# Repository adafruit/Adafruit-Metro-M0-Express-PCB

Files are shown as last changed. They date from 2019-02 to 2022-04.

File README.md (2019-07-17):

## Adafruit METRO M0 Express - designed for CircuitPython - ATSAMD21G18 PCB

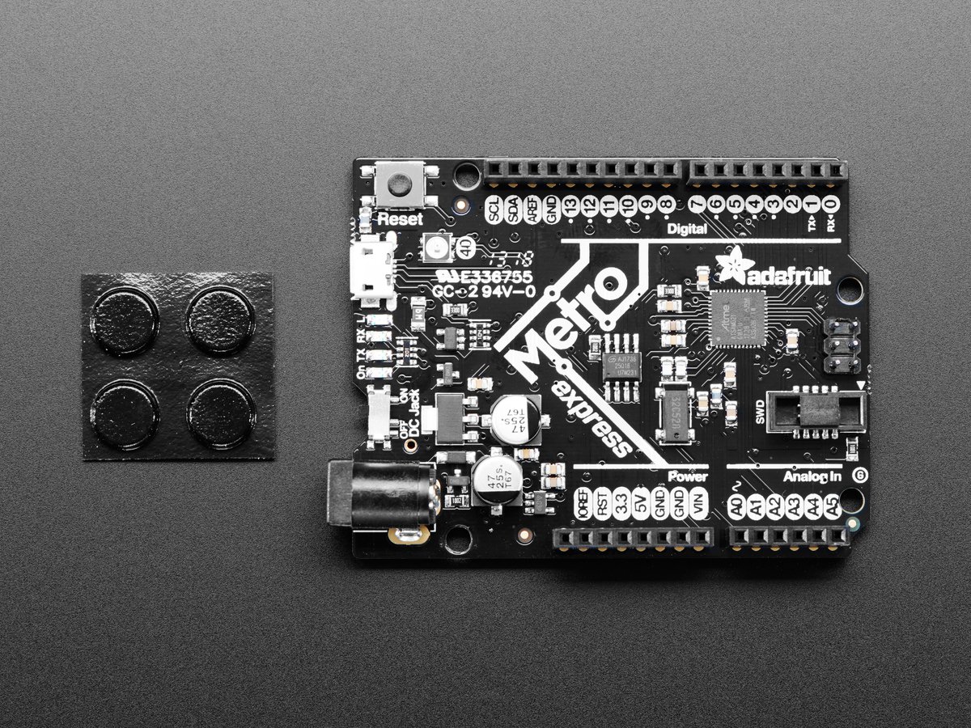
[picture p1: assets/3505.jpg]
<a href="http://www.adafruit.com/products/3505"><br/>
Click here to purchase one from the Adafruit shop</a>

PCB files for the Adafruit METRO M0 Express - designed for CircuitPython - ATSAMD21G18. Format is EagleCAD schematic and board layout
* https://www.adafruit.com/product/3505

### Description

Metro is our series of microcontroller boards for use with the Arduino IDE. This new **Metro M0 Express** board looks a whole lot like our [original Metro 328](https://www.adafruit.com/product/2488), but with a huge upgrade. Instead of the ATmega328, this Metro features a ATSAMD21G18 chip, an ARM Cortex M0+. It's our first Metro that is designed for use with CircuitPython! CircuitPython is our beginner-oriented flavor of MicroPython - and as the name hints at, its a small but full-featured version of the popular Python programming language specifically for use with circuitry and electronics.

Not only can you use CircuitPython, but the Metro M0 is also usable in the Arduino IDE.

At the Metro M0's heart is an ATSAMD21G18 ARM Cortex M0 processor, clocked at 48 MHz and at 3.3V logic, the same one used in the new [Arduino Zero](https://www.adafruit.com/products/2843). This chip has a whopping 256K of FLASH (8x more than the Atmega328) and 32K of RAM (16x as much)! This chip comes with built in USB so it has USB-to-Serial program & debug capability built in with no need for an FTDI-like chip.

 * **Power the METRO** with 7-9V polarity protected DC or the micro USB connector to any 5V USB source. The 2.1mm DC jack has an on/off switch next to it so you can turn off your setup easily. The METRO will automagically switch between USB and DC.
 * **METRO has 25 GPIO pins**, 12 of which are analog in, and one of which is a true analog out. There's a hardware SPI port, hardware I2C port and hardware UART. Logic level is 3.3V
 * **Native USB**, there's no need for a hardware USB to Serial converter as the Metro M0 has built in USB support. When used to act like a serial device, the USB interface can be used by any computer to listen/send data to the METRO, and can also be used to launch and update code via the bootloader. It can also act like a keyboard, mouse or MIDI device as well.
 * **Four indicator LEDs and one NeoPixel**, on the front edge of the PCB, for easy debugging. One green power LED, two RX/TX LEDs for data being sent over USB, and a red LED connected. Next to the reset button there is an RGB NeoPixel that can be used for any purpose.
 * **2 MB SPI Flash** storage chip is included on board. You can use the SPI Flash storage like a very tiny hard drive. When used in Circuit Python, the 2 MB flash acts as storage for all your scripts, libraries and files. When used in Arduino, you can read/write files to it, like a little datalogger or SD card, and then with our helper program, access the files over USB.
 * **Easy reprogramming**, comes pre-loaded with the [UF2 bootloader](https://learn.adafruit.com/adafruit-metro-m0-express-designed-for-circuitpython/uf2-bootloader), which looks like a USB storage key. Simply drag firmware on to program, no special tools or drivers needed! It can be used to load up CircuitPython, PXT/MakeCode or Arduino IDE (it is bossa-compatible)
Comes fully assembled with headers, tested, and with the UF2 bootloader loaded on. We also include 4 rubber bumpers to keep it from slipping off your desk. No soldering required to use, plug and play!

Good news, CircuitPython now comes preloaded!

[Check out our full guide for pinouts, schematics, drivers, instructions, Fritzing object, and more!](https://learn.adafruit.com/adafruit-metro-m0-express-designed-for-circuitpython)

### License

Adafruit invests time and resources providing this open source design, please support Adafruit and open-source hardware by purchasing products from [Adafruit](https://www.adafruit.com)!

Designed by Limor Fried/Ladyada for Adafruit Industries.

Creative Commons Attribution/Share-Alike, all text above must be included in any redistribution. See license.txt for additional details.

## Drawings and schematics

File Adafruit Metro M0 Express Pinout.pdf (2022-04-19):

# Adafruit Metro M0 Express

# https://www.adafruit.com/product/3505

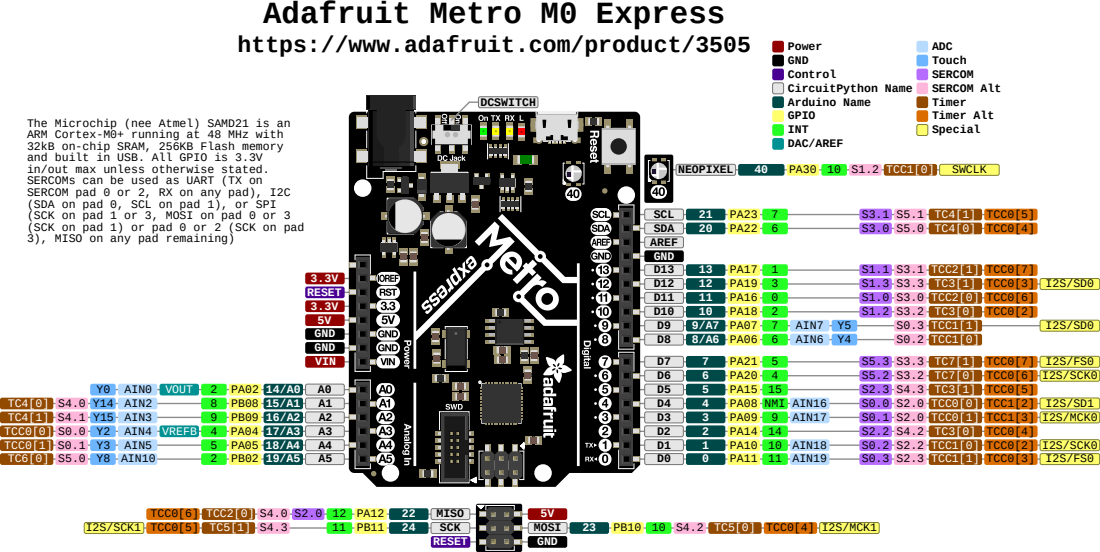
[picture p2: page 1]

The Microchip (nee Atmel) SAMD21 is an
ARM Cortex-M0+ running at 48 MHz with
32kB on-chip SRAM, 256KB Flash memory
and built in USB. All GPIO is 3.3V
in/out max unless otherwise stated.
SERCOMs can be used as UART (TX on
SERCOM pad 0 or 2, RX on any pad), I2C
(SDA on pad 0, SCL on pad 1), or SPI
(SCK on pad 1 or 3, MOSI on pad 0 or 3
(SCK on pad 1) or pad 0 or 2 (SCK on pad
3), MISO on any pad remaining)

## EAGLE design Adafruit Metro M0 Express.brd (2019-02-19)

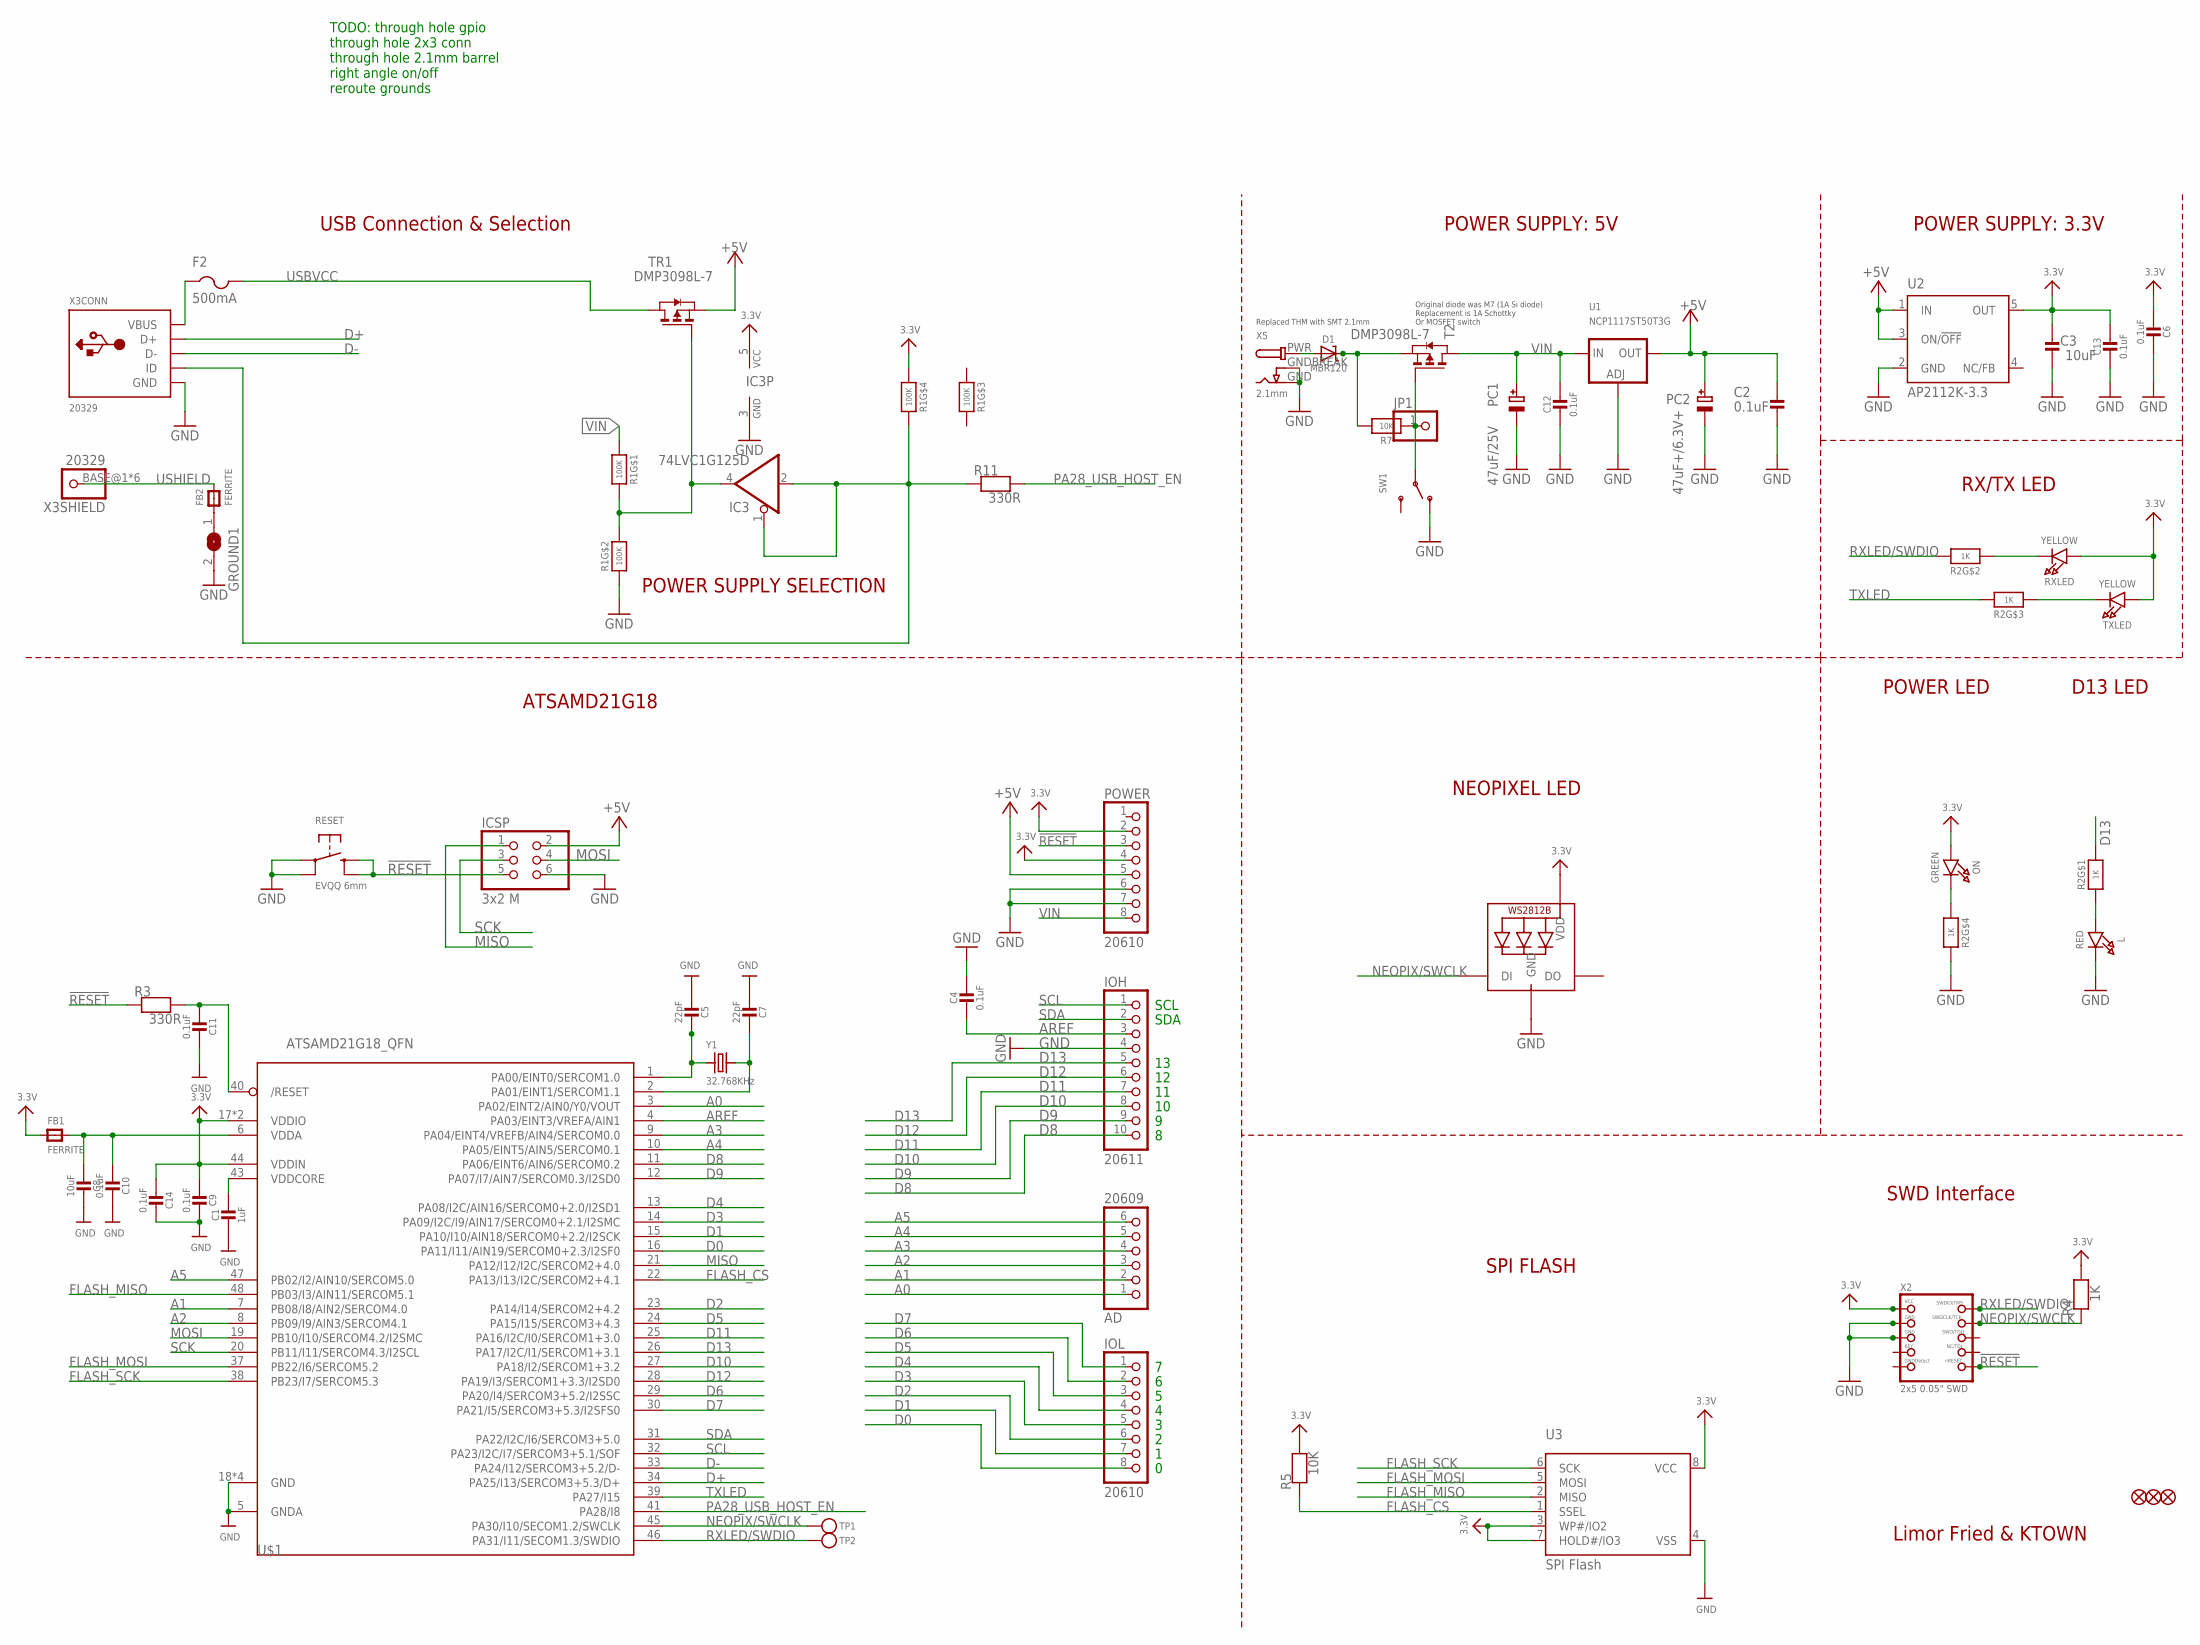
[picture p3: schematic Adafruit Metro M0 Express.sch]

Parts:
AD: 20609; 1X06_OVALWAVE
C1: 1uF; 0805-NO
C2, C4, C6, C9, C10, C11, C12, C13, C14: 0.1uF; 0805-NO
C3, C8: 10uF; 0805-NO
C5, C7: 22pF; 0805-NO
D1: MBR120; SOD-123
F2: 500mA; R1206
FB1, FB2: FERRITE; 0805-NO
FD1, FD2, FD3: FIDUCIAL_1MM
GROUND1: SJ
IC3: 74LVC1G125D; SOT23-5
ICSP: 3x2 M; 2X03_ROUND_70MIL
IOH: 20611; 1X10_OVALWAVE
IOL: 20610; 1X08_OVALWAVE
JP1: HEADER-1X1ROUND; 1X01_ROUND
L: RED; CHIPLED_0805_NOOUTLINE
LED1: WS2812B3535; LED3535
ON: GREEN; CHIPLED_0805_NOOUTLINE
PC1: 47uF/25V; PANASONIC_D
PC2: 47uF+/6.3V+; PANASONIC_D
POWER: 20610; 1X08_OVALWAVE
R1: 100K; RESPACK_4X0603
R2: 1K; RESPACK_4X0603
R3, R11: 330R; 0805-NO
R4: 1K; 0805-NO
R5, R7: 10K; 0805-NO
RESET: EVQQ 6mm; EVQ-Q2
RXLED: YELLOW; CHIPLED_0805_NOOUTLINE
SW1: SWITCH_SPDT; SPDT_SMT_SSSS811101
T2: DMP3098L-7; SOT-23
TP1, TP2: TESTPOINTROUND1.5MM; TESTPOINT_ROUND_1.5MM
TR1: DMP3098L-7; SOT-23
TXLED: YELLOW; CHIPLED_0805_NOOUTLINE
U1: NCP1117ST50T3G; SOT223-R
U2: AP2112K-3.3; SOT23-DBV
U3: SPI Flash; SOIC8_208MIL
U$1: ATSAMD21G18_QFN; TQFN48_7MM
X2: 2x5 0.05" SWD; 2X05_1.27MM_BOX_POSTS
X3: 20329; 4UCONN_20329_V2
X5: 2.1mm; DCJACK_2MM_PTH
Y1: 32.768KHz; CRYSTAL_8X3.8

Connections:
3.3V: C3.2, C6.2, C9.2, C13.1, C14.2, FB1.1, IC3.5 (VCC), LED1.2 (VDD), ON.A, POWER.2, POWER.4, R1.4 (1), R4.2, R5.2, RXLED.A, TXLED.A, U2.5 (OUT), U3.3 (WP#/IO2), U3.7 (HOLD#/IO3), U3.8 (VCC), U$1.17 (VDDIO), U$1.36 (VDDIO), U$1.44 (VDDIN), X2.1 (VCC)
!RESET: ICSP.5, POWER.3, R3.1, RESET.B (S), RESET.B' (S1), X2.10 (NRESET)
+5V: C2.2, ICSP.2, PC2.+, POWER.5, TR1.2 (S), U1.2 (OUT), U1.4 (OUT), U2.1 (IN), U2.3 (ON/!OFF)
A0: AD.1, U$1.3 (PA02/EINT2/AIN0/Y0/VOUT)
A1: AD.2, U$1.7 (PB08/I8/AIN2/SERCOM4.0)
A2: AD.3, U$1.8 (PB09/I9/AIN3/SERCOM4.1)
A3: AD.4, U$1.9 (PA04/EINT4/VREFB/AIN4/SERCOM0.0)
A4: AD.5, U$1.10 (PA05/EINT5/AIN5/SERCOM0.1)
A5: AD.6, U$1.47 (PB02/I2/AIN10/SERCOM5.0)
AREF: C4.2, IOH.3, U$1.4 (PA03/EINT3/VREFA/AIN1)
AVCC: C8.2, C10.2, FB1.2, U$1.6 (VDDA)
D0: IOL.8, U$1.16 (PA11/I11/AIN19/SERCOM0+2.3/I2SF0)
D1: IOL.7, U$1.15 (PA10/I10/AIN18/SERCOM0+2.2/I2SCK)
D2: IOL.6, U$1.23 (PA14/I14/SERCOM2+4.2)
D3: IOL.5, U$1.14 (PA09/I2C/I9/AIN17/SERCOM0+2.1/I2SMC)
D4: IOL.4, U$1.13 (PA08/I2C/AIN16/SERCOM0+2.0/I2SD1)
D5: IOL.3, U$1.24 (PA15/I15/SERCOM3+4.3)
D6: IOL.2, U$1.29 (PA20/I4/SERCOM3+5.2/I2SSC)
D7: IOL.1, U$1.30 (PA21/I5/SERCOM3+5.3/I2SFS0)
D8: IOH.10, U$1.11 (PA06/EINT6/AIN6/SERCOM0.2)
D9: IOH.9, U$1.12 (PA07/I7/AIN7/SERCOM0.3/I2SD0)
D10: IOH.8, U$1.27 (PA18/I2/SERCOM1+3.2)
D11: IOH.7, U$1.25 (PA16/I2C/I0/SERCOM1+3.0)
D12: IOH.6, U$1.28 (PA19/I3/SERCOM1+3.3/I2SD0)
D13: IOH.5, R2.8 (2), U$1.26 (PA17/I2C/I1/SERCOM1+3.1)
D+: U$1.34 (PA25/I13/SERCOM3+5.3/D+), X3.D+
D-: U$1.33 (PA24/I12/SERCOM3+5.2/D-), X3.D-
FLASH_CS: R5.1, U3.1 (SSEL), U$1.22 (PA13/I13/I2C/SERCOM2+4.1)
FLASH_MISO: U3.2 (MISO), U$1.48 (PB03/I3/AIN11/SERCOM5.1)
FLASH_MOSI: U3.5 (MOSI), U$1.37 (PB22/I6/SERCOM5.2)
FLASH_SCK: U3.6 (SCK), U$1.38 (PB23/I7/SERCOM5.3)
GND: C1.2, C2.1, C3.1, C4.1, C5.2, C6.1, C7.2, C8.1, C9.1, C10.1, C11.1, C12.2, C13.2, C14.1, GROUND1.2, IC3.3 (GND), ICSP.6, IOH.4, L.C, LED1.4 (GND), PC1.-, PC2.-, POWER.6, POWER.7, R1.2 (1), R2.5 (2), RESET.A, RESET.A' (P1), SW1.A (O), U1.1 (ADJ), U2.2 (GND), U3.4 (VSS), U$1.5 (GNDA), U$1.18 (GND), U$1.35 (GND), U$1.42 (GND), U$1.THERMAL (GND), X2.3 (GND), X2.5 (GND), X3.GND, X5.GND, X5.GNDBREAK
MISO: ICSP.1, U$1.21 (PA12/I12/I2C/SERCOM2+4.0)
MOSI: ICSP.4, U$1.19 (PB10/I10/SERCOM4.2/I2SMC)
unnamed: L.A, R2.1
unnamed: FB2.1, GROUND1.1
unnamed: ON.C, R2.4 (1)
unnamed: C5.1, U$1.1 (PA00/EINT0/SERCOM1.0), Y1.P$1 (1)
unnamed: R2.2 (1), RXLED.C
unnamed: C7.1, U$1.2 (PA01/EINT1/SERCOM1.1), Y1.P$4 (2)
unnamed: R2.3 (1), TXLED.C
unnamed: C11.2, R3.2, U$1.40 (/RESET)
unnamed: D1.A, X5.PWR
unnamed: IC3.1 (OE), IC3.2 (I), R1.5 (2), R11.1, X3.ID
unnamed: IC3.4 (O), R1.7 (2), R1.8 (2), TR1.3 (G)
unnamed: JP1.1, R7.1, SW1.B, T2.3 (G)
unnamed: D1.C, R7.2, T2.2 (S)
NEOPIX/SWCLK: LED1.1 (DI), R4.1, TP1.P$1, U$1.45 (PA30/I10/SECOM1.2/SWCLK), X2.4 (SWDCLK)
PA28_USB_HOST_EN: R11.2, U$1.41 (PA28/I8)
RXLED/SWDIO: R2.7 (2), TP2.P$1, U$1.46 (PA31/I11/SECOM1.3/SWDIO), X2.2 (SWDIO)
SCK: ICSP.3, U$1.20 (PB11/I11/SERCOM4.3/I2SCL)
SCL: IOH.1, U$1.32 (PA23/I2C/I7/SERCOM3+5.1/SOF)
SDA: IOH.2, U$1.31 (PA22/I2C/I6/SERCOM3+5.0)
TXLED: R2.6 (2), U$1.39 (PA27/I15)
USBVCC: F2.2, TR1.1 (D)
USHIELD: FB2.2, X3.BASE@1 (1), X3.BASE@2 (1), X3.SPRT@1 (1), X3.SPRT@2 (1), X3.SPRT@3 (1), X3.SPRT@4 (1)
VBUS: F2.1, X3.VBUS
VDDCORE: C1.1, U$1.43 (VDDCORE)
VIN: C12.1, PC1.+, POWER.8, R1.1, T2.1 (D), U1.3 (IN)

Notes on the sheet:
SDA
SCL
Limor Fried & KTOWN
Original diode was M7 (1A Si diode) Replacement is 1A Schottky Or MOSFET switch
Replaced THM with SMT 2.1mm
POWER SUPPLY: 5V
USB Connection & Selection
POWER SUPPLY: 3.3V
POWER LED
ATSAMD21G18
POWER SUPPLY SELECTION
D13 LED
RX/TX LED
NEOPIXEL LED
SPI FLASH
SWD Interface
TODO: through hole gpio through hole 2x3 conn through hole 2.1mm barrel right angle on/off reroute grounds

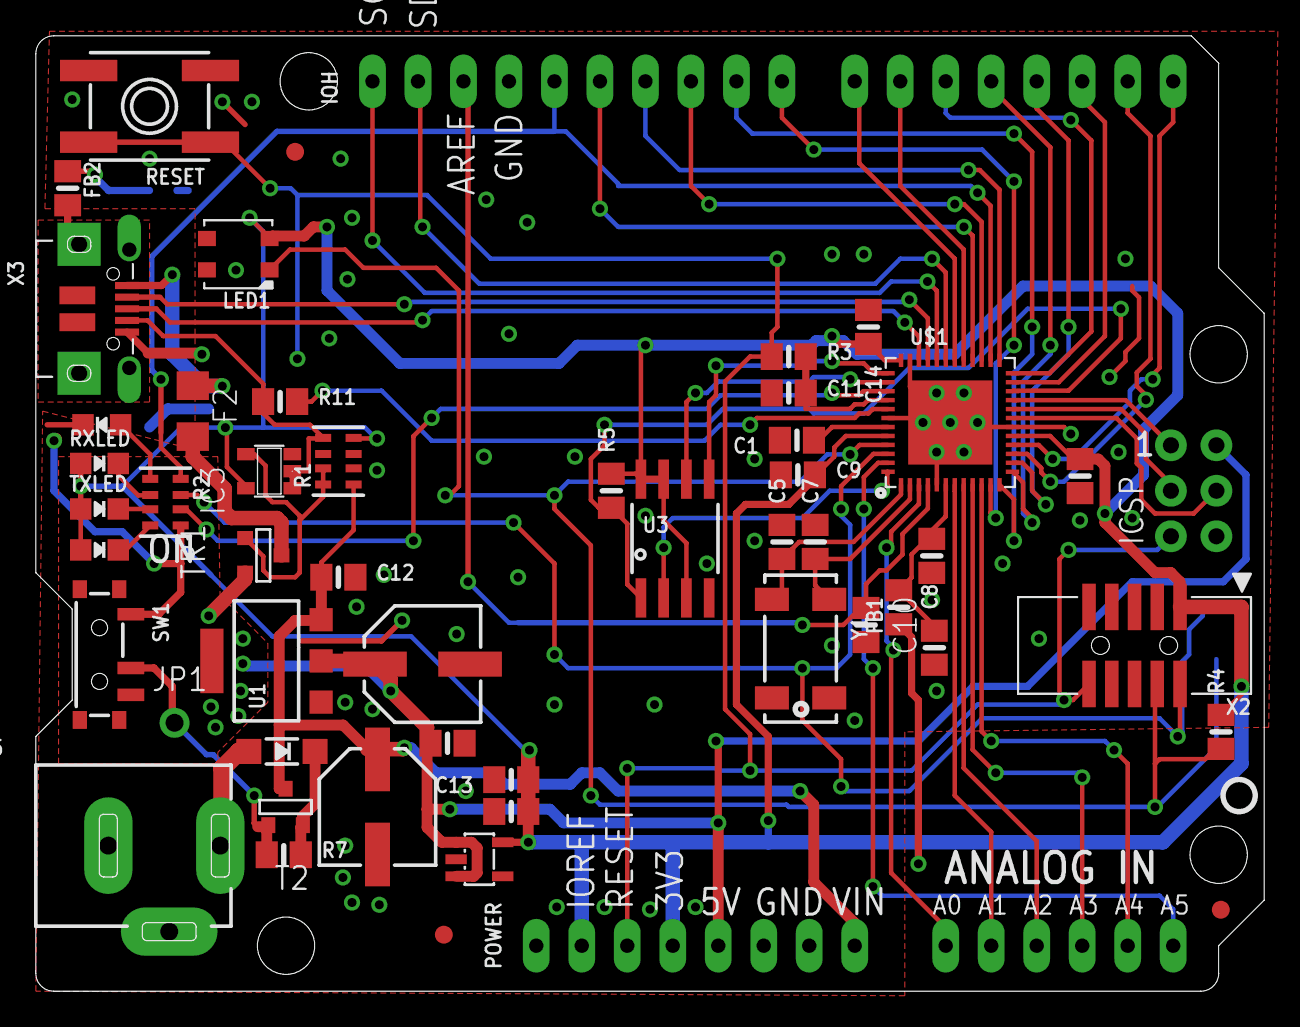
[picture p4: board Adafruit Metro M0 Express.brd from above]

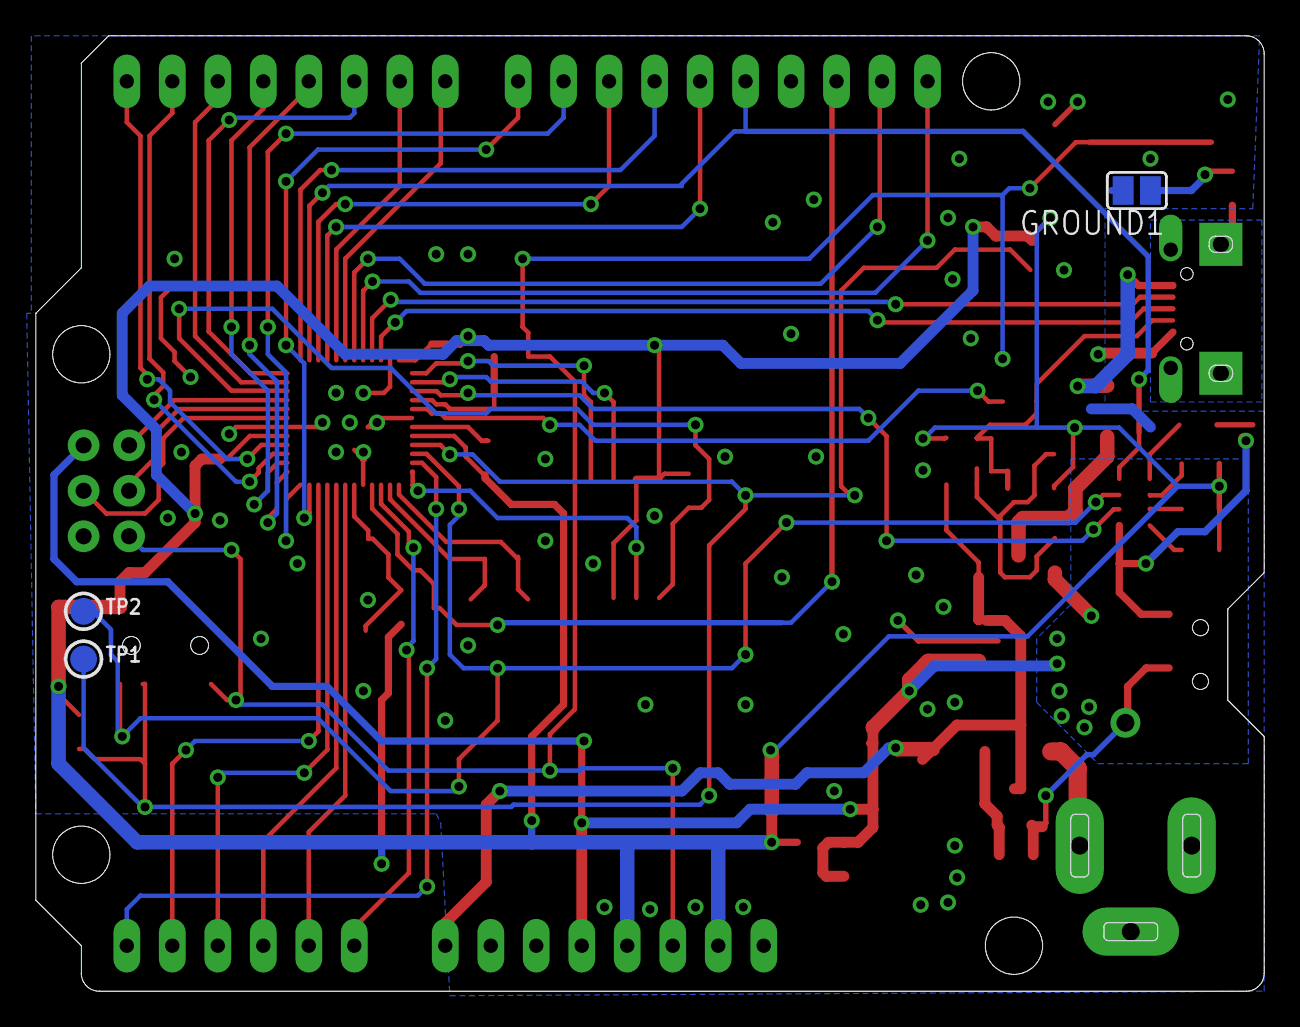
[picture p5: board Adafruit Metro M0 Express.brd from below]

Board: 2 copper layers, 68.6 x 53.3 mm, 60 parts (4 on the bottom side), 59 nets.

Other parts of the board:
U$11: METRO_M0_BACK
U$14: PCBFEAT-REV-040
U$30: METRO_M0_FRONT

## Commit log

2019-02-19 Deleting file to update.
    [Adafruit Metro M0 Express.brd]
2019-02-19 Updating board files.
    [Adafruit Metro M0 Express.brd, Adafruit Metro M0 Express.sch]
2019-07-17 updated to use cookiecutter for pcb repos

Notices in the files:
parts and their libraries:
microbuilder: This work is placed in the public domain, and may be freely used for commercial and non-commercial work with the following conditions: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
